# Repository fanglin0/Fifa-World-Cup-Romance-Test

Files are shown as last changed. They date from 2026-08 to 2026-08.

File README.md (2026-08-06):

# FIFA World Cup Player Love Compatibility Test

PLAYABLE HERE https://wokwi.com/projects/471554640484162561

##  What this project is
<a href="https://github.com/user-attachments/assets/daa91c57-6042-4519-ba92-43361ac078c5">WITHDRAWN FROM OUTPOST</a>
<a href="https://cad.onshape.com/documents/731b43eee40e1793ce4f1bee/w/3bcd84ddf1f4906279decfc5/e/f6a80c11e3a2f9d7e2fb46b3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">OnShape link</a>

Inspired by <a href="https://www.reddit.com/r/AustralianNostalgia/comments/1fx5e6g/old_school_love_compatibility_tests_random_i_know/">old school romance compaitbility tests (based on names)</a> I built a old-school style, hand-held console like hardware with Arduino 32 as the display to match the player to their soulmate (from the cast of the 2026 FIFA world cup players trending all over social media). With a series of personality questions the user will be matched to their perfect partner from the world cup, and be able to navigate and reset through answer choices with the buttons.

The Arduino handles the logic, the PCB wires everything together, and the OLED will display the game alongisde the buttons. 

## Project Architecture
                USB-C
                   │
                   ▼
        ┌─────────────────┐
        │ Arduino Nano    │
        │ ESP32           │
        │                 │
        │ Runs all code   │
        └─────────────────┘
           │  │  │  │
           │  │  │  │
           │  │  │  └── D5 → RESET button
           │  │  └───── D4 → RIGHT button
           │  └──────── D3 → OK button
           └─────────── D2 → LEFT button

           │
           ├── SDA → OLED SDA
           └── SCL → OLED SCL

           │
           ├── 5V → OLED VCC
           └── GND → OLED GND

## Software Flow 
Power On
   │
   ▼
Title Screen
   │
   ▼
Intro Screen
   │
   ▼
12 Quiz Questions
   │
   ▼
Fake Analysis Screen
   │
   ▼
Compatibility Result
   │
   ▼
Football Profile
   │
   ▼
Ending Screen
   │
   ▼
Reset

## Image examples and Demo

<a href="https://youtu.be/dARFpi-PZSk">Video demo here</a>
Screenshot 2026-07-03 at 6 18 37 PM
Screenshot 2026-07-03 at 6 07 43 PM
Screenshot 2026-07-07 at 8 47 31 PM

---

## Why I made this project
To learn hardware in a unique project that I would enjoy using myself! Also practicing C++ as it's somewhat?? similar to Java

## How I made this project

Followed various tutorials for kicad, the C tutoial for eprosnality quiz to script the logic behind the love compatiblity quiz, and then learning how to use onshape to rig a simple 3d case to make the model resemble my vision of a handheld console more. Trying to get it to work on my demo was hard

---

## Challenges I faced
Trying to get the LONG script to come together, had to troubleshoot various times
Also, trying to 3d model in onshape. I struggled to navigate the basic menu and a lot of parts in the project was harder than expected, as I had to learn them from scratch. It took a lot more cramming than expected to get in before deadline :')

##AI Declaration
ChatGPT was used to debug code when I got stuck, as I'm a complete beginner with almost no background in hardware except for a chaser. Claude was also used a lot in terms of debugging linking the hardware arduino 32 w/ my code, so it's understdanble if hours are dedcuated!

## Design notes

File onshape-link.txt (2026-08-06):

https://cad.onshape.com/documents/731b43eee40e1793ce4f1bee/w/3bcd84ddf1f4906279decfc5/e/f6a80c11e3a2f9d7e2fb46b3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

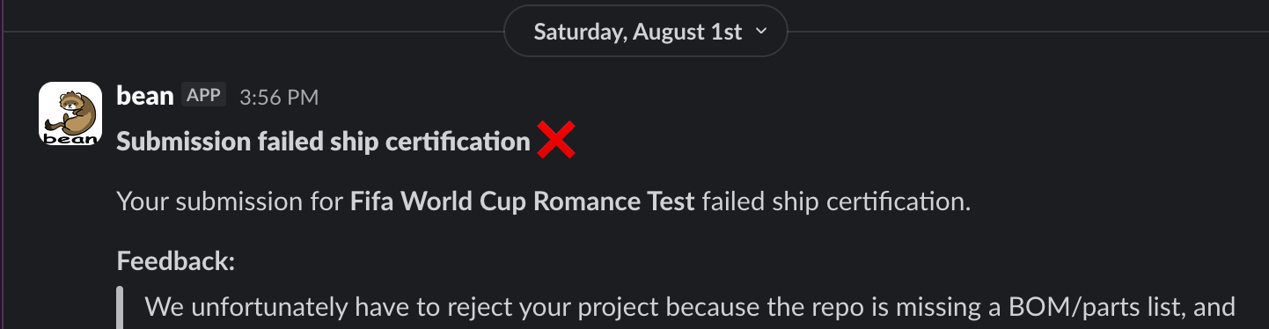
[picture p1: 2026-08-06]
image.png

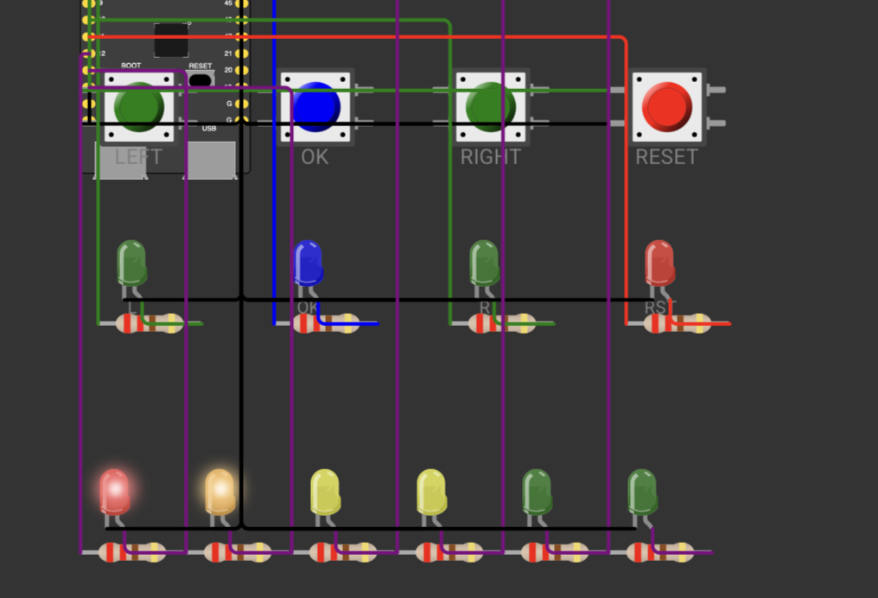
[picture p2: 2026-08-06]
screenshots/Screenshot 2026-08-05 at 8.12.43 PM.png

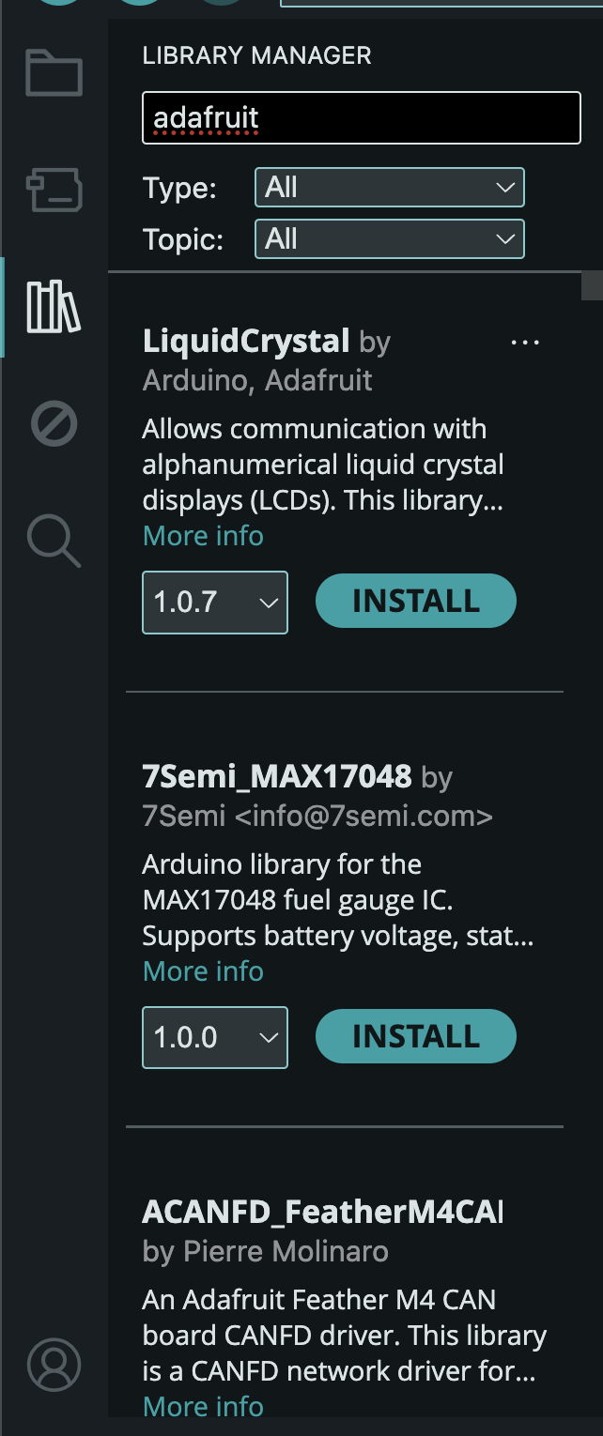
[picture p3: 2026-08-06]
screenshots/Screenshot 2026-07-15 at 1.27.12 PM.png

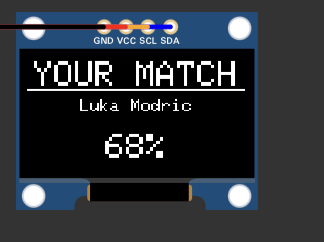
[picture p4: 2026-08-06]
screenshots/Screenshot 2026-08-05 at 8.04.36 PM.png

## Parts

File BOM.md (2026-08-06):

# Bill of Materials — World Cup Love Machine

Derived from `outpost.kicad_sch` / `outpost.kicad_pcb` (6 placed components) plus the
mechanical and firmware requirements.

## Electronics

| Ref | Qty | Part | Spec | KiCad footprint |
|-----|-----|---|---|---|
| A1 | 1 | Arduino Nano ESP32 | ESP32-S3, USB-C, 3.3 V logic | `Connector_PinHeader_1.00mm:PinHeader_2x15_P1.00mm_Horizontal` — **see Known issues** |
| J3 | 1 | 4-pin header, 2.54 mm vertical | Carries the I2C OLED: 5V, GND, SDA, SCL | `Connector:FanPinHeader_1x04_P2.54mm_Vertical` |
| SW1 | 1 | Tactile push button, 6 mm THT | LEFT | `Button_Switch_THT:SW_PUSH_6mm` |
| SW2 | 1 | Tactile push button, 6 mm THT | OK | `Button_Switch_THT:SW_PUSH_6mm` |
| SW3 | 1 | Tactile push button, 6 mm THT | RIGHT | `Button_Switch_THT:SW_PUSH_6mm` |
| SW4 | 1 | Tactile push button, 6 mm THT | RESET | `Button_Switch_THT:SW_PUSH_6mm` |

No resistors or capacitors are required. The buttons use the ESP32's internal
pull-ups (`INPUT_PULLUP` in `WorldCupLoveMachine.ino`) and are wired
button-to-GND, so no external pull-ups are on the board.

## Off-board parts

| Qty | Part | Spec |
|-----|---|---|
| 1 | SSD1306 OLED module | 128×64, I2C, address `0x3C`, 4-pin (monochrome) |
| 1 | Custom PCB | 2-layer; fab with `outpost.kicad_pcb` + `outpost-PTH.drl` / `outpost-NPTH.drl` |
| 1 | 3D-printed enclosure | Print from `model.stl` (source: `step.step`) |
| 1 | USB-C cable | Power + programming |
| 1 | Pin header / socket strip for A1 | Pitch must match the board — see Known issues |

## Pin mapping

From `WorldCupLoveMachine.ino` and the schematic net labels:

| Signal | Arduino pin | Goes to |
|---|---|---|
| LEFT | D2 | SW1 |
| OK | D3 | SW2 |
| RIGHT | D4 | SW3 |
| RESET | D5 | SW4 |
| SDA | A4 | J3 (OLED) |
| SCL | A5 | J3 (OLED) |
| 5V | VUSB/5V | J3 (OLED) |
| GND | GND | J3, SW1–SW4 |

J3's net order in the schematic runs 5V, GND, SDA, SCL. Many SSD1306 breakouts
ship as GND, VCC, SCL, SDA — **wire by label, not by position.**

## Firmware build

Board package: **Arduino ESP32 Boards** (`arduino:esp32`), board *Arduino Nano ESP32*
(FQBN `arduino:esp32:nano_nora`).

Libraries (Library Manager):

- Adafruit SSD1306
- Adafruit GFX Library
- Adafruit BusIO (pulled in as a dependency)

`Wire` ships with the core. Build with the Arduino IDE, or:

```sh
arduino-cli lib install "Adafruit SSD1306" "Adafruit GFX Library"
arduino-cli compile --fqbn arduino:esp32:nano_nora .
arduino-cli upload  --fqbn arduino:esp32:nano_nora -p /dev/ttyACM0 .
```

The sketch folder name must stay `WorldCupLoveMachine` to match the `.ino`.

## Simulator (no hardware needed)

The firmware runs unmodified in [Wokwi](https://wokwi.com) — see [`sim/README.md`](sim/README.md)
for setup, and [`sim/diagram.json`](sim/diagram.json) for the wiring.

Board: `board-esp32-s3-devkitc-1`. The Arduino Nano ESP32 is an ESP32-S3, so the button
pins (2/3/4/5) and the default-`Wire` OLED init carry over with no code changes.

Wokwi link: _(paste the Share URL here once the project is saved)_

These parts exist **only in the simulation** — they are not on the PCB:

| Qty | Part | Purpose |
|-----|---|---|
| 4 | LED | One per button, flashes on press (GPIO 6, 7, 10, 11) |
| 6 | LED | Compatibility "score meter" bar (GPIO 12–17) |
| 10 | 220 Ω resistor | One per LED |

`leds.h` sets `DEMO_LEDS` to 0 when `ARDUINO_NANO_ESP32` is defined, so hardware builds
compile the LED module away entirely and never drive those GPIOs. If you ever do want
lights on a real board, that guard is the single place to change.

## Known issues

- **A1 footprint pitch mismatch.** The schematic symbol's default footprint is
  `Module:Arduino_Nano`, but the placed A1 instance uses a 2×15 header at
  **1.00 mm** pitch (pads on a 1 mm grid in `outpost.kicad_pcb`). An Arduino Nano
  ESP32 has 2.54 mm pitch pins with 15.24 mm between rows, so it will not fit
  these holes. Re-assign A1 to `Module:Arduino_Nano` and re-route before ordering
  boards, or plan to hand-wire the module.
- `parts.zip` contains the two drill files, not a parts list.

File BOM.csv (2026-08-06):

Ref | Qty | Part | Description | Manufacturer | MPN / Product ID | Supplier | Purchase Link | Unit Price (USD) | Ext Price (USD) | Notes
A1 | 1 | Arduino Nano ESP32 with headers | ESP32-S3 MCU board; USB-C; 3.3 V logic; runs all firmware | Arduino | ABX00083 | DigiKey | https://www.digikey.com/en/products/detail/arduino/ABX00083/21219775 | 19.30 | 19.30 | Also at store.arduino.cc/products/nano-esp32-with-headers. See Known Issues: the A1 footprint on this PCB is 1.00 mm pitch and does NOT match this board's 2.54 mm pins.
U1 | 1 | Monochrome 0.96in 128x64 OLED - STEMMA QT | SSD1306 I2C display; address 0x3C; 5 V tolerant | Adafruit | 326 | Adafruit | https://www.adafruit.com/product/326 | 17.50 | 17.50 | Off-board; connects to J3. Any 4-pin I2C SSD1306 128x64 module works - wire by label (5V/GND/SDA/SCL), not by pin position.
SW1-SW4 | 4 | Tactile Button switch 6 mm THT (20-pack) | LEFT / OK / RIGHT / RESET buttons; footprint SW_PUSH_6mm | Adafruit | 367 | Adafruit | https://www.adafruit.com/product/367 | 2.50 | 2.50 | Price is for the 20-pack; you need 4. No external pull-ups - firmware uses INPUT_PULLUP and buttons go to GND.
J3 | 1 | Break-away 0.1in 36-pin male header strip (10-pack) | Snap off 4 pins for the OLED connector | Adafruit | 392 | Adafruit | https://www.adafruit.com/product/392 | 4.95 | 4.95 | Price is for the 10-strip pack; you need 4 pins.
- | 1 | Premium Female/Female jumper wires 40 x 6in | Connects J3 on the PCB to the OLED module | Adafruit | 266 | Adafruit | https://www.adafruit.com/product/266 | 3.95 | 3.95 | You need 4 wires.
PCB1 | 1 | Custom 2-layer PCB 40.0 x 37.5 mm | Fabricate from outpost-gerbers.zip | JLCPCB | - | JLCPCB | https://jlcpcb.com/ | 2.00 | 2.00 | ~$2 for 5 pcs plus shipping. Alternatives: pcbway.com, oshpark.com. Upload outpost-gerbers.zip directly.
- | 1 | USB Type A to Type C cable - 1 m | Power and programming | Adafruit | 4474 | Adafruit | https://www.adafruit.com/product/4474 | 4.95 | 4.95 | Any USB-C data cable works.
CASE1 | 1 | 3D-printed enclosure | Print from model.stl (CAD source: step.step) | - | - | JLC3DP | https://jlc3dp.com/ | 5.00 | 5.00 | ~$5 in PLA/resin from a print service, or free on your own printer. Source geometry: step.step.
 |  |  |  |  |  |  |  | Total | 60.15 | One-off build cost, excluding shipping and tax. Prices checked 2026-08-05.

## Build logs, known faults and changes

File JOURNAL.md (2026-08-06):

# FIFA World Cup Player Love Compatibility Test Journal (total: 

##  7/3/26 ~4.5 hours (recorded on Lapse)
I created the schematic and pcb, wired everything together. I went through a couple designs and had to troubleshoot with friends to finish the design. I looked for the easiest way to get my deaisgn up and running and landed on the Arudino ESP 32.
Screenshot 2026-07-03 at 6 18 37 PM
Screenshot 2026-07-03 at 3 00 02 PM

##  7/4/26 ~3 hours 
I started researching how to code the logic behind my love compatibility test, started looking for and researching C++ tutorials for my Arduino. I also realized that I cannot test my script as I do not (yet) have a in person arduino to connect to my laptop and test on, and the online (free) ones I've tested turns out to be too slow to simulate. So I'm just stringing together tutorial code and hoping it works.
Screenshot 2026-07-03 at 7 19 39 PM
Screenshot 2026-07-03 at 6 19 22 PM

## 7/5/26 ~6 hours
Finished my schematic pcb and made sure all the wires worked. I trial and error'ed my way through the wiring and then realized there's different layers with the guidance of my friend. I started expeirmenitng and making functions in game.h, had to troubleshoot with chatgpt. 

## 7/6 ~6 hours
Making the personality, the players, questions, and the fucntions in the game to track user motion from the input in buttons. Made ui with animation with the display text

## 7/7 ~4 hours (Lapse partly)
Debugging code. Attempting to rig a 3d case, handheld display like cover for the arduino. 
Screenshot 2026-07-07 at 8 47 31 PM

## 7/9 ~3 hours GOT REJECTED FROM OUTPOST LMAO
Made a BOM.csv file as per reviewer note. Was told there were multiple traces in your PCB routing that are >90 degrees (whcih ) will cause the routing to either break or act as a fuse). idk how that works and messed around trying to make routing better. Follwoed <a href="https://forum.kicad.info/t/approaching-pcb-track-routing-for-a-newbie/36302/8">this old forum post, and tried to follow guide to make everything on layer and as horizontal as possible.

## 7/10 ~1.8 hours
Made a model.stl file for my onshape case holder thingy, expanded the tracing a bit so changed the shape up as well

## 7/15 ~1.5 hours
Which arudino package is ts...?? . Had to go into <a href="https://docs.arduino.cc/hardware/nano-esp32/">Boards Manager</a> and installed the "Arduino ESP32 Boards" package and Adafruit SSD1306 isn't there. use ai help

## 7/16 ~4 hours
`multiple definition of drawCenteredText`. Ok so the display is NOT working. Realized, like my reviewers said, it would not compile as is and arduino doesnt run. Chatgpt said wowki would work. I put my code in and it didn't run? Chatgpt told me my drawing functions were broken, also my repo was empty .ino AND left them in ui.cpp, so the linker was seeing two of everything. i had to make one singular function and move all my functions into one

## 7/17-20 ~8 hours
为什么是 black!! the i2c_scanner sketch (File > Examples > Wire) and display at 0x30 hardcoded that in `display.begin()`. I went down <a href="https://learn.adafruit.com/monochrome-oled-breakouts">a forum rabbit hole and learned very one</a>of these little breakouts prints its pins in a different order — mine is GND/VCC/SCL/SDA but my J3 header in the schematic is 5V/GND/SDA/SCL, which are completely different. I'd followed chatgpt instruction and assumed it was the same but I guess I'd fry something?? if i continue wiring by the label

## 7/21 ~3 hours
<a href="https://docs.arduino.cc/built-in-examples/digital/InputPullupSerial">Turns out with `INPUT_PULLUP` was flipped</a>. The pin sits HIGH and pressing it pulls it to LOW. My chatgpt code `if (digitalRead(pin) == HIGH)` was backwards the entire time :sob:. Then one press was skipping through like 6 questions at once??????? because loop() runs thousands of times a second and holds the button the whole way  which made my laptop rly hot. <a href="ttps://docs.arduino.cc/built-in-examples/digital/Debounce">Fixed</a> so it only fired on the HIGH->LOW *edge*.

## 7/22 ~3 hours

The blinking heart on the title screen worked!!!! froze the whole program while it blinked bc of delay() Same thing killed the loading bar. i realized ur not supposed to wait but <a href="https://docs.arduino.cc/built-in-examples/digital/BlinkWithoutDelay">  `millis() - lastTime > interval` every frame and only act when i's true. Redid it with heartTimer and loadingTimer as `unsigned long`, which the tutorial says has to be unsigned long or it overflows after 32 seconds. Now the buttons still respond while things are animating. Now things kinda work w the questions but they cut off

## 7/23 ~5 hours
Adafruit GFX just breaks lines in the middle of a word and then happily keeps drawing past the bottom of the panel into nowhere, so half my player descriptions were invisible. <a href=" https://learn.adafruit.com/adafruit-gfx-graphics-l
ibrary"Wrote my own drawWrappedText that counts 21 chars per line</a>, walks *backwards* to the last space so it breaks between words, and takes a maxLines so it physically can't run off the screen. If it runs out of room and there's still text left it chops the last few chars and puts "..." on the end

## 7/24 ~4 hours
Im. so sick oh my lord. "YOUR MATCH!" at text size 2 is 132px wide and the screen is 128, so it was clipped on BOTH sides — dropped the exclamation mark and it fits. The soccer balls were at y=10 which put them straight on top of "WORLD CUP",moved them to y=48 down by the heart. The profile screen was the worst, description and warning wereoverlapping each other, so I put everything on an8px grid (10/18/26 for the description, 36/44/52 for the warning) and used "! " instead of writing out "Warning:" — that saves 7 characters which is the difference between all 12 warnings fitting and 6 of them getting cut off. 

<!-- screenshot: wokwi sim showing the profile screen fitting -->

## 7/25 ~4.5 hours
Made the actual matching work. Every player has 6 trait numbers (kindness, humor, confidence, creativity, loyalty, ambition) and so does the user by the end of the quiz, so I loop all 12 players, add up the absolute differences, and whoever is closest wins. Everyone was getting Messi no matter what they answered — my traits were all still 0 because I was writing them in the wrong place, they only counted when you hit OK, not while scrolling. Then map() to turn a difference into a percent (https://docs.arduino.cc/language-reference/en/functions/math/map/), backwards on purpose so a *small* difference gives a *big* percent.

## 7/26 ~.75 hours
Added `random(-4, 5)` on top so result percentages wobbles a bit and clamped it to 60-99. 

## 7/27 ~4 hours
Wrote all 12 questions and all 12 player profiles, which took longer than any of the code. And then I reqalized out I could put `\n` like in Java inside the question string and println just handles the line break, so "Your biggest\nstrength?" splits itself. Accoridng to https://docs.arduino.cc/learn/programming/memory-guide/ String is bad on embedded and you should use PROGMEM BUT it compiles and runs fine on the ESP32 rn so I'm leaving it.

## 7/28 ~4 hours

Added LEDs to the sim — 4 that flash when you press a button, 6 as a little score meter bar. These are NOT on my actual PCB, they just make the Wokwi demo look alive. Wrapped the whole thing in `#if DEMO_LEDS` and set that to 0 when `ARDUINO_NANO_ESP32` is defined, so a real hardware build compiles the entire module away instead of driving pins that don't exist. Picking the GPIOs was annoying — had to dodge I2C (8, 9), my buttons (2-5),UART0 (43, 44), USB (19, 20), the strapping pins(0, 45, 46) and the flash/PSRAM pins (26-37). Landed on 6, 7, 10, 11 and 12-17. Also 10 resistorsbecause apparently you cannot just put an LED straight across a pin.

## 7/29 ~2 hours
So Claude tells me after troublsheeoitng that I'd have to reassign A1 to `Module:Arduino_Nano` and re-route, or hand-wire it bc my A1 footprint is a 2x15 header at **1.00 mm** pitch but a real Nano ESP32 has 2.54 mm pins with 15.24 mm between the rows but im gonna leave it 4 now. That's a problem for when I have to build it lmao

## 7/31 ~2 hours
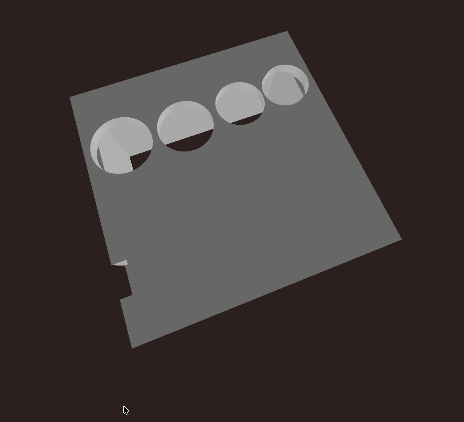
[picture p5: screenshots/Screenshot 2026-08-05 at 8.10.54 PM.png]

3D case, changed a little to have spaces for the lights 

## 8/2 ~2 hours

Rejected from Horizons for missing BOM list with updated stuff Made one through claude

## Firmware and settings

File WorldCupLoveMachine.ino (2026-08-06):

// calls all files to run! refer to this as main
#include "ui.h"
#include "game.h"
#include "questions.h"
#include "players.h"

#include <Arduino.h>
#include <Adafruit_GFX.h>
#include <Adafruit_SSD1306.h>


// Draw Centered Text


void drawCenteredText(
    Adafruit_SSD1306 &display,
    String text,
    int y,
    int size)
{

    display.setTextSize(size);

    int16_t x1;
    int16_t y1;
    uint16_t w;
    uint16_t h;

    display.getTextBounds(
        text,
        0,
        0,
        &x1,
        &y1,
        &w,
        &h
    );

    int x = (128 - w) / 2;

    display.setCursor(x, y);

    display.print(text);

}


const int CHARS_PER_LINE = 21;  
const int LINE_HEIGHT    = 8;

int drawWrappedText(
    Adafruit_SSD1306 &display,
    String text,
    int x,
    int y,
    int maxLines)
{

    display.setTextSize(1);

    int lines = 0;
    int pos   = 0;
    int len   = text.length();

    while(pos < len && lines < maxLines)
    {

        int take = len - pos;


        // Break between words where we can


        if(take > CHARS_PER_LINE)
        {

            take = CHARS_PER_LINE;

            int brk = take;

            while(brk > 0 && text.charAt(pos + brk) != ' ')
                brk--;

            if(brk > 0)
                take = brk;

        }

        String line = text.substring(pos, pos + take);

        line.trim();

        pos += take;


        // Skip the space we broke on


        while(pos < len && text.charAt(pos) == ' ')
            pos++;


        // Out of room but not out of text


        if(lines == maxLines - 1 && pos < len)
        {

            while(line.length() + 3 > (unsigned int)CHARS_PER_LINE)
                line = line.substring(0, line.length() - 1);

            line += "...";

        }

        display.setCursor(x, y + lines * LINE_HEIGHT);

        display.print(line);

        lines++;

    }

    return lines;

}


// Progress Bar


void drawProgressBar(
    Adafruit_SSD1306 &display,
    int progress)
{

    if(progress < 0)
        progress = 0;

    if(progress > 100)
        progress = 100;

    display.drawRect(
        14,
        50,
        100,
        8,
        WHITE
    );

    int width = map(
        progress,
        0,
        100,
        0,
        98
    );

    display.fillRect(
        15,
        51,
        width,
        6,
        WHITE
    );

}


// Pixel Heart


void drawHeart(
    Adafruit_SSD1306 &display,
    int x,
    int y,
    bool filled)
{

    if(filled)
    {

        display.fillCircle(x+2,y+2,2,WHITE);
        display.fillCircle(x+6,y+2,2,WHITE);

        display.fillTriangle(
            x,
            y+3,
            x+8,
            y+3,
            x+4,
            y+9,
            WHITE
        );

    }

    else
    {

        display.drawCircle(x+2,y+2,2,WHITE);
        display.drawCircle(x+6,y+2,2,WHITE);

        display.drawLine(
            x,
            y+3,
            x+4,
            y+9,
            WHITE
        );

        display.drawLine(
            x+8,
            y+3,
            x+4,
            y+9,
            WHITE
        );

    }

}


// Tiny Soccer Ball


void drawSoccerBall(
    Adafruit_SSD1306 &display,
    int x,
    int y)
{

    display.drawCircle(
        x,
        y,
        6,
        WHITE
    );

    display.fillCircle(
        x,
        y,
        2,
        WHITE
    );

    display.drawPixel(x,y-6,WHITE);
    display.drawPixel(x+4,y-4,WHITE);
    display.drawPixel(x-4,y-4,WHITE);

    display.drawPixel(x+5,y+2,WHITE);
    display.drawPixel(x-5,y+2,WHITE);

    display.drawPixel(x,y+6,WHITE);

}


// Title Animation


void animateTitle()
{

    if(millis() - heartTimer > 450)
    {

        heartVisible = !heartVisible;

        heartTimer = millis();

    }

}


// Loading Animation


void animateLoading()
{

    if(millis() - loadingTimer > 35)
    {

        loadingProgress++;

        if(loadingProgress > 100)
        {

            loadingProgress = 100;

        }

        loadingTimer = millis();

    }

}


// TITLE SCREEN


void drawTitle(Adafruit_SSD1306 &display)
{
    animateTitle();

    display.clearDisplay();

    // Top border
    display.drawLine(0, 0, 127, 0, WHITE);
    display.drawLine(0, 63, 127, 63, WHITE);

    // Soccer balls flank the heart. At y=10 they sat on top of
    // "WORLD CUP", which spans x=10..117 at size 2.
    drawSoccerBall(display, 20, 48);
    drawSoccerBall(display, 108, 48);

    drawCenteredText(display, "WORLD CUP", 8, 2);
    drawCenteredText(display, "LOVE MACHINE", 28, 1);

    if (heartVisible)
    {
        drawHeart(display, 58, 44, true);
    }
    else
    {
        drawHeart(display, 58, 44, false);
    }

    drawCenteredText(display, "PRESS OK", 55, 1);

    display.display();
}


// INTRO SCREEN


void drawIntro(Adafruit_SSD1306 &display)
{

    display.clearDisplay();

    drawCenteredText(display, "WELCOME!", 2, 2);

    drawWrappedText(
        display,
        "Find your dream man from the football world leagues!",
        2,
        24,
        4
    );

    display.display();

}


// QUESTION SCREEN


void drawQuestion(Adafruit_SSD1306 &display)
{

    display.clearDisplay();

    // Question number

    display.setTextSize(1);

    display.setCursor(0, 0);

    display.print("Question ");

    display.print(currentQuestion + 1);

    display.print("/");

    display.print(QUESTION_COUNT);

    // Divider

    display.drawLine(0, 10, 127, 10, WHITE);

    // Question

    display.setCursor(0, 16);

    display.println(
        questions[currentQuestion].question
    );

    // Current Choice

    display.drawRoundRect(
        8,
        40,
        112,
        18,
        3,
        WHITE
    );

    display.setCursor(18, 46);

    display.print("< ");

    display.print(
        questions[currentQuestion]
            .choices[currentChoice]
    );

    display.print(" >");

    display.display();

}


// LOADING SCREEN


void drawLoading(Adafruit_SSD1306 &display)
{
    animateLoading();

    display.clearDisplay();

    drawCenteredText(display, "ANALYZING...", 4, 2);

    drawSoccerBall(display, 18, 28);

    display.setTextSize(1);

    if (loadingProgress < 25)
    {
        display.setCursor(35, 25);
        display.print("Reading");
        display.setCursor(35, 35);
        display.print("personality...");
    }
    else if (loadingProgress < 50)
    {
        display.setCursor(35, 25);
        display.print("Comparing");
        display.setCursor(35, 35);
        display.print("chemistry...");
    }
    else if (loadingProgress < 75)
    {
        display.setCursor(35, 25);
        display.print("Searching");
        display.setCursor(35, 35);
        display.print("FIFA database...");
    }
    else
    {
        display.setCursor(35, 25);
        display.print("Finding your");
        display.setCursor(35, 35);
        display.print("soulmate...");
    }

    drawProgressBar(display, loadingProgress);

    display.display();
}
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

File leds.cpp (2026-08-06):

// Demo LEDs for the Wokwi simulator.
#include "leds.h"
#include "game.h"

#if DEMO_LEDS
// Pin assignments; Chosen to avoid I2C (8, 9), the buttons (2-5),
// UART0 (43, 44), USB (19, 20), the strapping pins
// (0, 45, 46) and flash/PSRAM (26-37).
static const int buttonLedPins[BUTTON_LED_COUNT] = {

    6,   // LEFT
    7,   // OK
    10,  // RIGHT
    11   // RESET

};

static const int meterLedPins[METER_LED_COUNT] = {

    12, 13, 14, 15, 16, 17

};
// Button LED flash timers

const unsigned long ledFlashTime = 120;

static unsigned long ledOffAt[BUTTON_LED_COUNT] = { 0, 0, 0, 0 };
// Init

void initLeds()
{

    for(int i = 0; i < BUTTON_LED_COUNT; i++)
    {

        pinMode(buttonLedPins[i], OUTPUT);

        digitalWrite(buttonLedPins[i], LOW);

        ledOffAt[i] = 0;

    }

    for(int i = 0; i < METER_LED_COUNT; i++)
    {

        pinMode(meterLedPins[i], OUTPUT);

        digitalWrite(meterLedPins[i], LOW);

    }

}
// Flash One Button LED
//
// Non-blocking - updateLeds() turns it back off.

void flashButtonLed(int index)
{

    if(index < 0 || index >= BUTTON_LED_COUNT)
        return;

    digitalWrite(buttonLedPins[index], HIGH);

    ledOffAt[index] = millis() + ledFlashTime;

}
// Score Meter

static void setMeter(int litCount)
{

    for(int i = 0; i < METER_LED_COUNT; i++)
    {

        digitalWrite(
            meterLedPins[i],
            i < litCount ? HIGH : LOW
        );

    }

}
// Per-Frame Update

void updateLeds()
{


    // Expire any button flashes


    for(int i = 0; i < BUTTON_LED_COUNT; i++)
    {

        if(ledOffAt[i] != 0 && millis() >= ledOffAt[i])
        {

            digitalWrite(buttonLedPins[i], LOW);

            ledOffAt[i] = 0;

        }

    }


    // Meter


    switch(gameState)
    {
        // Chase while "analyzing"

        case LOADING:

            setMeter(0);

            digitalWrite(
                meterLedPins[
                    (loadingProgress / 4) % METER_LED_COUNT
                ],
                HIGH
            );

            break;
        // Fill to the match percentage
        //
        // compatibilityScore is clamped to 60..99 by
        // calculateCompatibility(), so this maps exactly
        // onto 1..METER_LED_COUNT lit LEDs.

        case RESULT:
        case PROFILE:

            setMeter(
                map(
                    compatibilityScore,
                    60,
                    99,
                    1,
                    METER_LED_COUNT
                )
            );

            break;

        default:

            setMeter(0);

            break;

    }

}

#else
// Real hardware has no LEDs - everything compiles away.

void initLeds() {}

void updateLeds() {}

void flashButtonLed(int) {}

#endif

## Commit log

2026-08-06 final commit everyhting works ahahahhaha
    [outpost-NPTH.drl, outpost-PTH.drl]
2026-08-06 added onshape link, gerbers.zip, and bom.csv
    [BOM.csv]
